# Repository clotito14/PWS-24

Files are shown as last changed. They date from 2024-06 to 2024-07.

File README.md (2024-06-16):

# Linear Power Supply Project
## Chase Lotito - Lotito Labs - 06.16.2024

The following project is to learn more about circuit design and PCB design via making a linear power supply.

During this project, I used online resources for the structure of the circuit and KiCAD for schematics and the PCB.

### Design Requirements:
* Input: +120VAC 60Hz connects from mains.
* Output: Variable 0-20VDC @ 3A max.

### Circuit Structure:

120VAC INPUT -> STEP-DOWN TRANSFORMER -> 16VAC -> FULL-BRIDGE RECTIFIER -> FILTER CAPACITOR -> VOLTAGE REGULATOR -> 0-20VDC OUTPUT

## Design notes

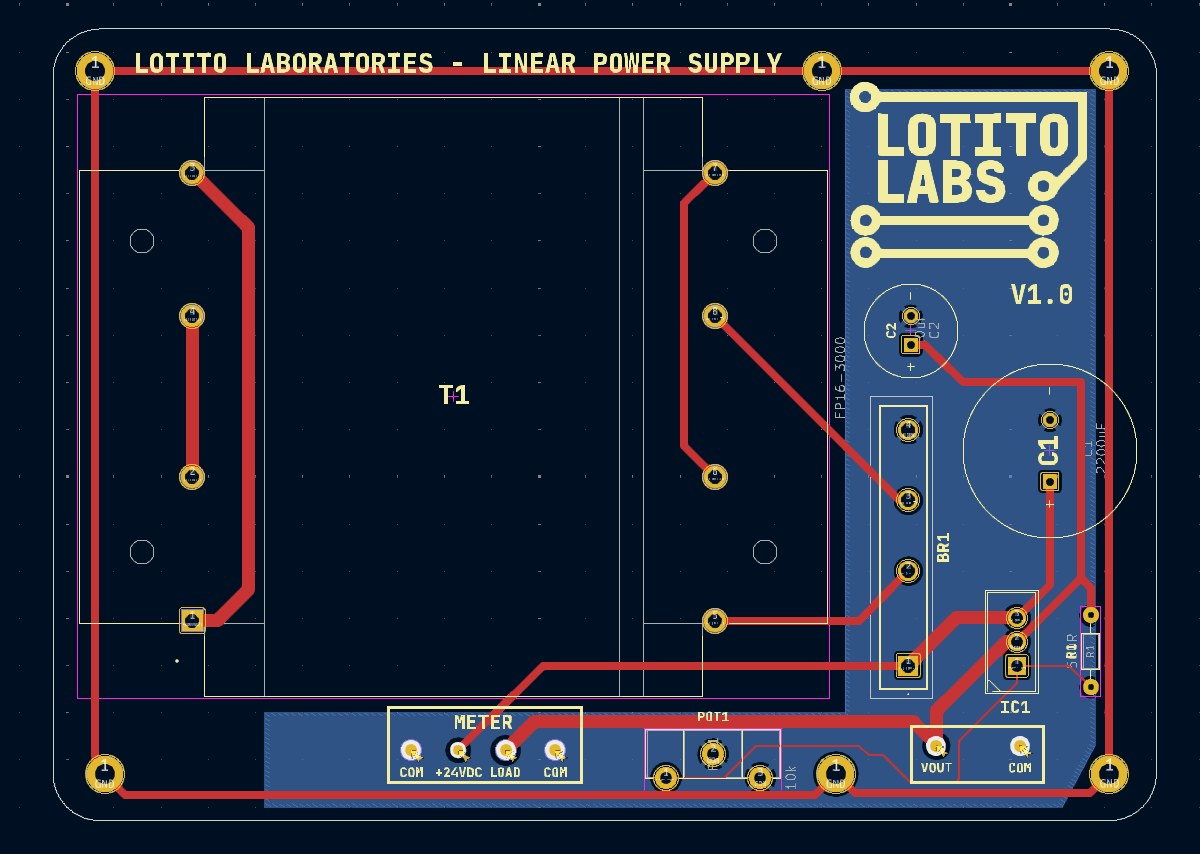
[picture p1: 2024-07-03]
photos/PWS PCB Layout.png

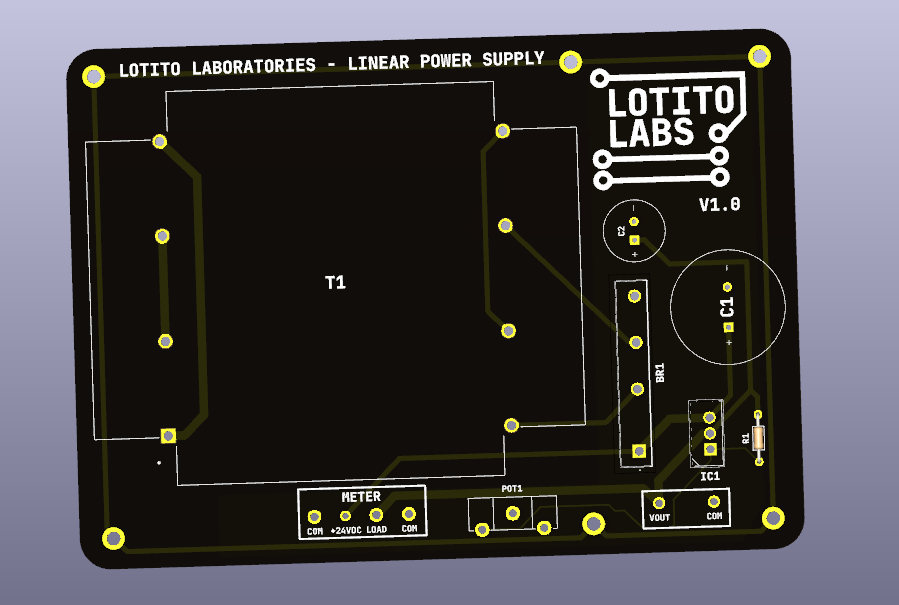
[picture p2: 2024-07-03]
photos/PWS Circuit 3D.png

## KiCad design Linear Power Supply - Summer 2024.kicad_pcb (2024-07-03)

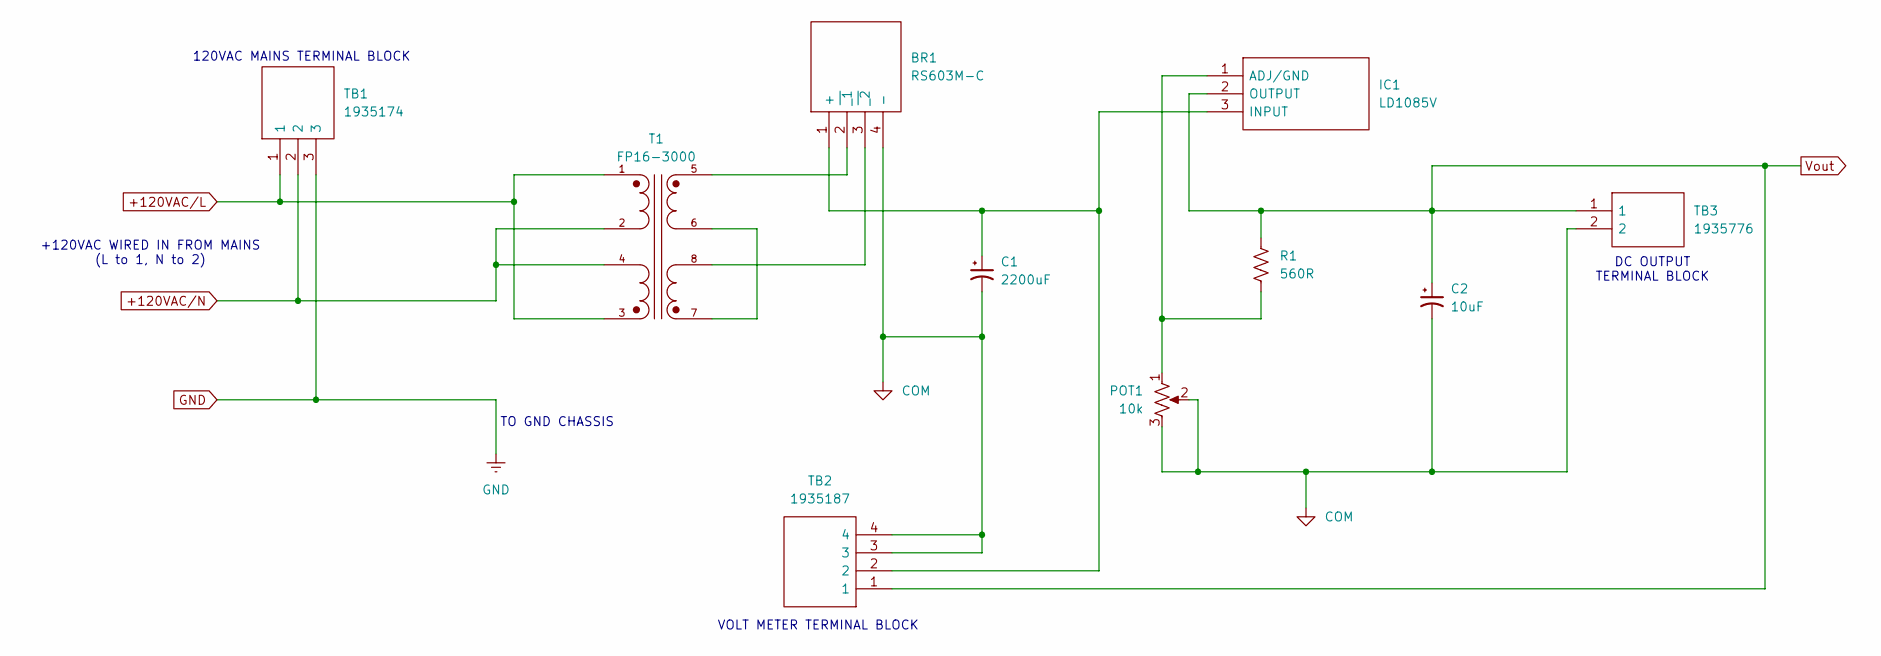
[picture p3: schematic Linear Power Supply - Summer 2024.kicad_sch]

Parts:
BR1: RS603M-C; RS603MC; Manufacturer_Part_Number RS603M-C; Mouser Part Number 583-RS603M
C1: 2200uF; 228SAK050M
C2: 10uF; Small Electrolytic Capacitor
IC1: LD1085V; TO255P460X1020X2008-3P; Manufacturer_Part_Number LD1085V; Mouser Part Number 511-LD1085V
POT1: 10k; 1935174
R1: 560R; R_Axial_DIN0204_L3.6mm_D1.6mm_P7.62mm_Horizontal
T1: FP16-3000; XFMR_FP16-3000
TB1: 1935174; Manufacturer_Part_Number 1935174; Mouser Part Number 651-1935174
TB2: 1935187; Manufacturer_Part_Number 1935187; Mouser Part Number 651-1935187
TB3: 1935776; Manufacturer_Part_Number 1935776; Mouser Part Number 651-1935776

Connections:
+120VAC/L: T1.1, T1.3, TB1.1
+120VAC/N: T1.2, T1.4, TB1.2
COM: BR1.4 (-), C1.2, C2.2, POT1.2, POT1.3, TB2.3, TB2.4, TB3.2
GND: TB1.3
unnamed: BR1.1 (+), C1.1, IC1.3 (INPUT), TB2.2
unnamed: BR1.2 (~_1), T1.5
unnamed: BR1.3 (~_2), T1.8
unnamed: IC1.1 (ADJ/GND), POT1.1, R1.2
unnamed: T1.6, T1.7
Vout: C2.1, IC1.2 (OUTPUT), R1.1, TB2.1, TB3.1

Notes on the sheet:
DC OUTPUT TERMINAL BLOCK
120VAC MAINS TERMINAL BLOCK
VOLT METER TERMINAL BLOCK
+120VAC WIRED IN FROM MAINS (L to 1, N to 2)
TO GND CHASSIS

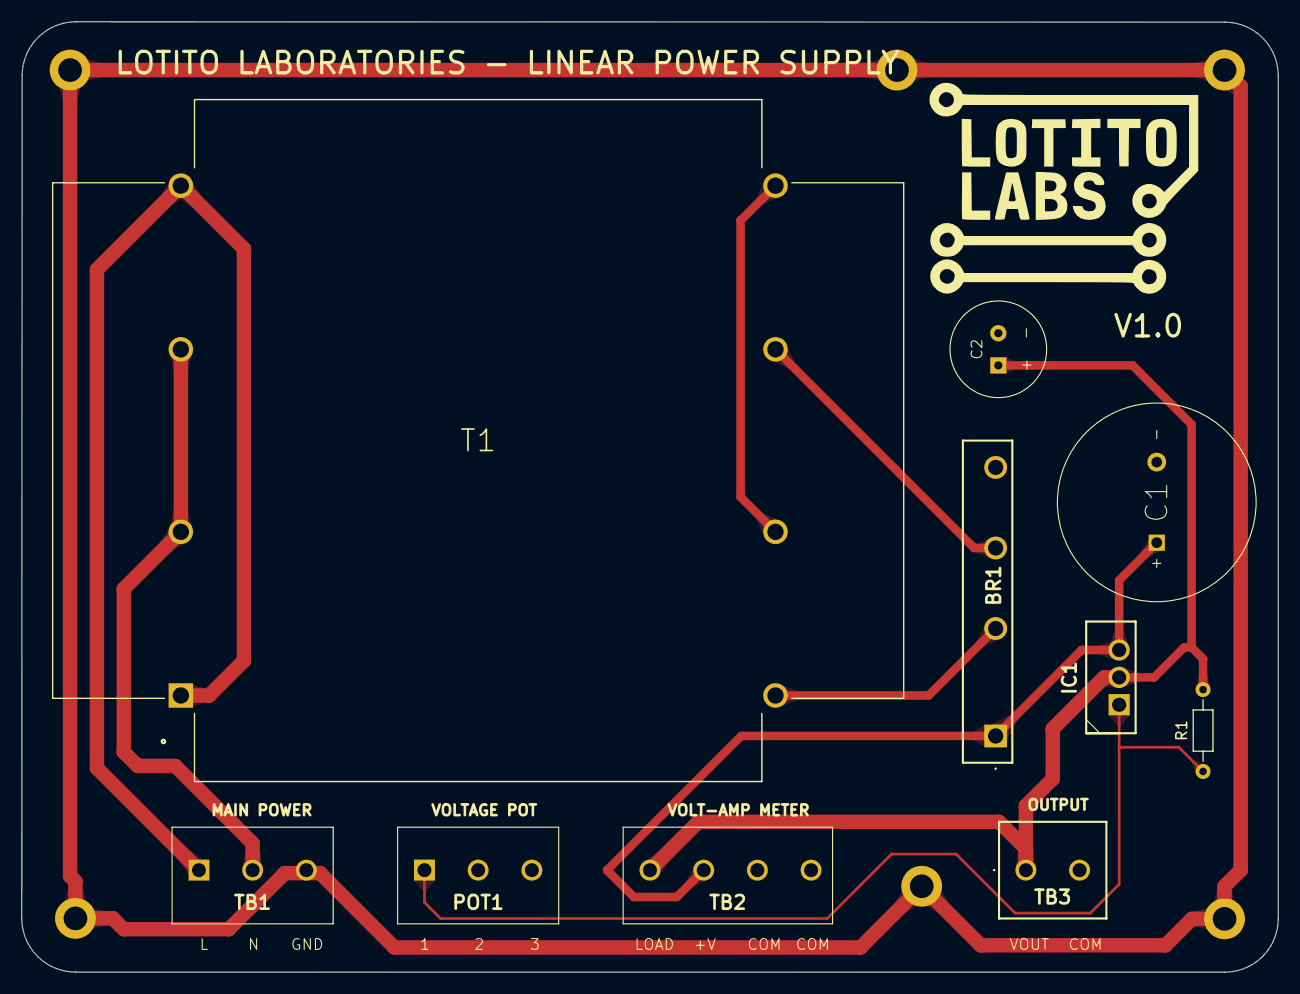
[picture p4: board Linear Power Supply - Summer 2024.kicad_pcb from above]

Board: 2 copper layers, 117.0 x 88.5 mm, 10 parts (0 on the bottom side), 9 nets.

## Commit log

2024-06-16 First Commit.
    [Linear Power Supply - Summer 2024.kicad_pcb, Linear Power Supply - Summer 2024.kicad_sch]
2024-06-17 Big push on the PCB layout. I think ready to send to JLC or OSH...
    [Linear Power Supply - Summer 2024-B_Cu.gbl, Linear Power Supply - Summer 2024-B_Mask.gbs, Linear Power Supply - Summer 2024-B_Paste.gbp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]
2024-07-03 Finished PCB design...
    [Linear Power Supply - Summer 2024-B_Cu.gbl, Linear Power Supply - Summer 2024-B_Mask.gbs, Linear Power Supply - Summer 2024-B_Paste.gbp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]
